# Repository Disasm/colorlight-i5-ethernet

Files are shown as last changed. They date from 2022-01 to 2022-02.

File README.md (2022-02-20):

# `colorlight-i5-ethernet`

Dual gigabit Ethernet interface board for [Colorlight i5 Extension Board](https://github.com/wuxx/Colorlight-FPGA-Projects). 

This board is based on [i5ether](https://github.com/kazkojima/colorlight-i5-tips/) project by
[@kazkojima](https://github.com/kazkojima).

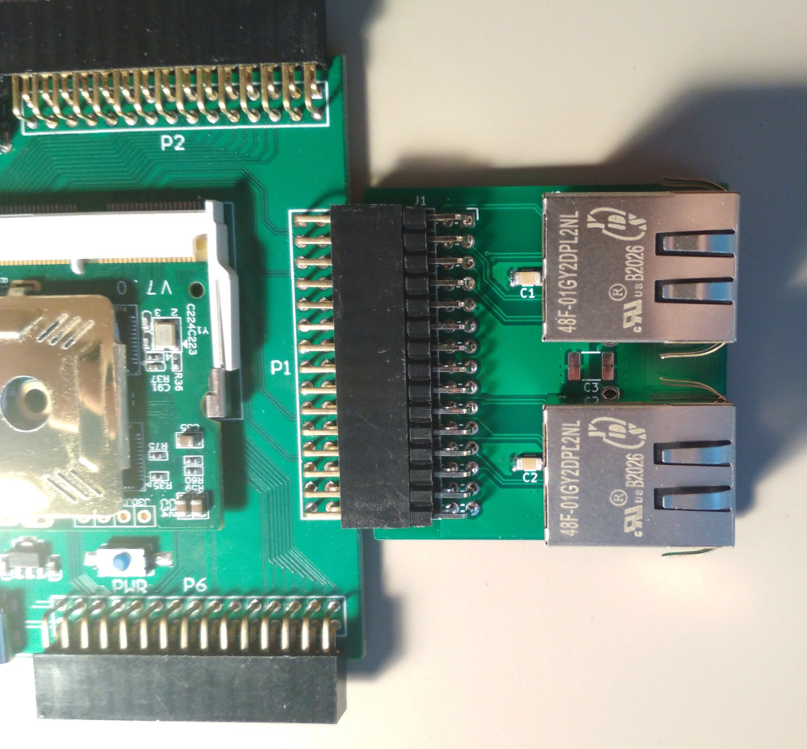
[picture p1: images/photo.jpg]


Manufactured on JLCPCB (see `gerbers` directory). Tested with the [colorlight_i5.py example](https://github.com/litex-hub/litex-boards/blob/master/litex_boards/targets/colorlight_i5.py)
from LiteX.

# Bill of Materials

| Item | Part # | LCSC Part # | Qty |
|---|---|---|-----|
| Connector (J1) | X6521WR-2x15H-C30D60 | [C725927] | 1 |
| Ethernet connector (J2, J3) | 48F-01GY2DPL2NL | [C123172] | 2 |
| Capacitor (C1, C2) | GRM319R71H104KA01D | [C86047] | 2 |
| Capacitor (C3) | 1812B472K202CT | [C304036] | 1 |

[C123172]: https://lcsc.com/product-detail/Ethernet-Connectors-Modular-Connectors-RJ45-RJ11_Shanghai-YDS-Tech-48F-01GY2DPL2NL_C123172.html
[C86047]: https://lcsc.com/product-detail/Multilayer-Ceramic-Capacitors-MLCC-SMD-SMT_Murata-Electronics-GRM319R71H104KA01D_C86047.html
[C304036]: https://lcsc.com/product-detail/Multilayer-Ceramic-Capacitors-MLCC-SMD-SMT_Walsin-Tech-Corp-1812B472K202CT_C304036.html
[C725927]: https://lcsc.com/product-detail/Pin-Headers_XKB-Connectivity-X6521WR-2x15H-C30D60_C725927.html

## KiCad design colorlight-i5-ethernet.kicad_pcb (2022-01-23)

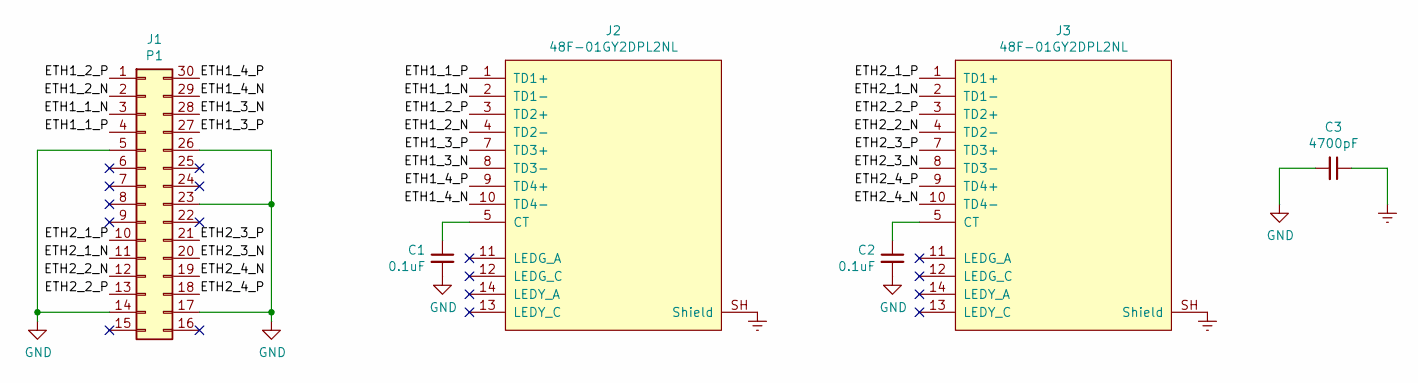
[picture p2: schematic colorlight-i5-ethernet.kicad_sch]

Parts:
C1, C2: 0.1uF; C_1206_3216Metric
C3: 4700pF; C_1812_4532Metric; MFR.Part # 1812B472K202CT; LCSC Part # C304036
J1: P1; PinHeader_2x15_P2.54mm_Horizontal_PMOD
J2, J3: 48F-01GY2DPL2NL; LCSC Part # C123172

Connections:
/ETH1_1_N: J1.3, J2.2 (TD1-)
/ETH1_1_P: J1.4, J2.1 (TD1+)
/ETH1_2_N: J1.2, J2.4 (TD2-)
/ETH1_2_P: J1.1, J2.3 (TD2+)
/ETH1_3_N: J1.28, J2.8 (TD3-)
/ETH1_3_P: J1.27, J2.7 (TD3+)
/ETH1_4_N: J1.29, J2.10 (TD4-)
/ETH1_4_P: J1.30, J2.9 (TD4+)
/ETH2_1_N: J1.11, J3.2 (TD1-)
/ETH2_1_P: J1.10, J3.1 (TD1+)
/ETH2_2_N: J1.12, J3.4 (TD2-)
/ETH2_2_P: J1.13, J3.3 (TD2+)
/ETH2_3_N: J1.20, J3.8 (TD3-)
/ETH2_3_P: J1.21, J3.7 (TD3+)
/ETH2_4_N: J1.19, J3.10 (TD4-)
/ETH2_4_P: J1.18, J3.9 (TD4+)
Earth: C3.1, J2.SH (Shield), J3.SH (Shield)
GND: C1.2, C2.2, C3.2, J1.5, J1.14, J1.17, J1.23, J1.26
unnamed: C1.1, J2.5 (CT), J2.6 (CT)
unnamed: C2.1, J3.5 (CT), J3.6 (CT)

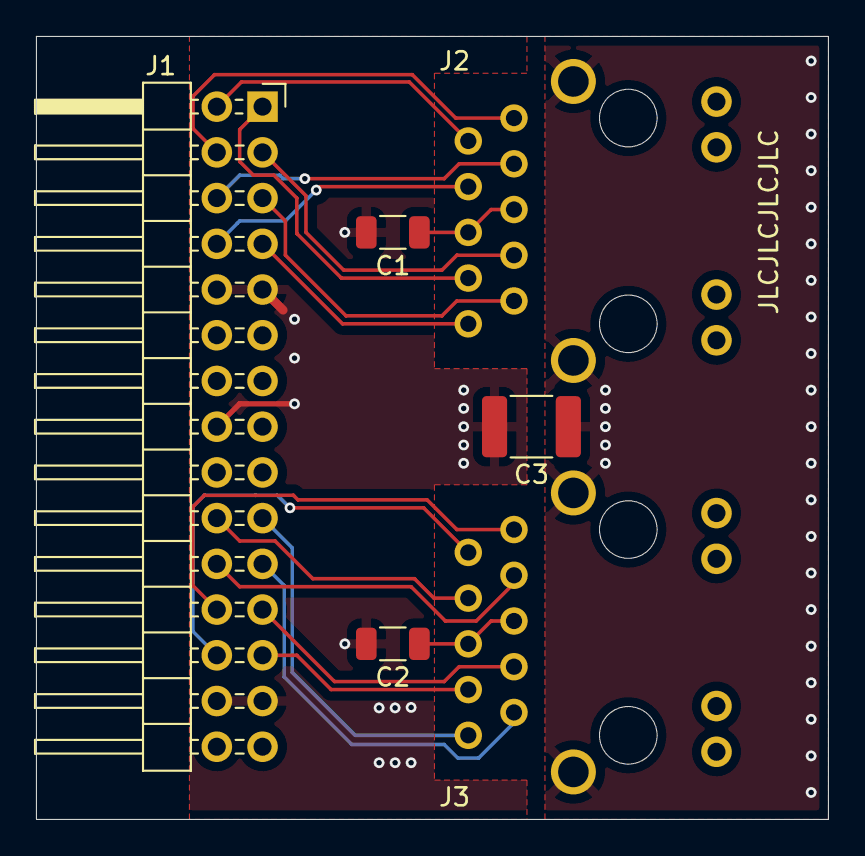
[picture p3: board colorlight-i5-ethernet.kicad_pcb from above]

Board: 2 copper layers, 44.0 x 43.5 mm, 6 parts (0 on the bottom side), 20 nets.

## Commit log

2021-01-06 Initial version
    [colorlight-i5-ethernet.kicad_pcb, colorlight-i5-ethernet.sch]
2022-01-23 Update to KiCad 6.0, prepare for production
    [colorlight-i5-ethernet.kicad_pcb, colorlight-i5-ethernet.kicad_sch, colorlight-i5-ethernet.sch]
2022-01-23 Add gerbers
    [colorlight-i5-ethernet-B_Cu.gbl, colorlight-i5-ethernet-B_Mask.gbs, colorlight-i5-ethernet-B_Silkscreen.gbo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]
